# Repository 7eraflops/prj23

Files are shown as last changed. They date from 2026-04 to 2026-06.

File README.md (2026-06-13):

# 3-Phase 12-Channel ESP32 Energy Monitor

A custom ESP32-based energy meter measuring up to 12 channels across a 3-phase supply, integrated with Home Assistant via MQTT.

## Current Status
- End-to-end firmware flow is working on ESP32 DevKit: provisioning -> Wi-Fi -> MQTT -> HA discovery -> telemetry -> command handling.
- ATM90E32 real driver path is implemented (`register map`, `SPI transport`, `ATM90E32Sensor` implementing `IEnergySensor`).
- DevKit-only mock-IC path is implemented on a dedicated testing branch.
- Custom PCB and physical calibration are pending hardware availability.

## Overview
- **Measurement**: Uses the ATM90E32AS metering IC to monitor up to 12 circuits (11 used in current planned deployment).
- **Microcontroller**: ESP32-S3.
- **Integration**: Home Assistant MQTT Auto-Discovery for automatic entity configuration.
- **Provisioning**: Local captive portal and web server for Wi-Fi and MQTT setup.
- **Testing**: Uses mock sensor paths for software development before final hardware is available.

## Hardware
- **Custom PCB**: Currently in development.
- **MCU**: ESP32-S3
- **Metering IC**: ATM90E32AS
- **Sensors**: Current Transformers (CT Clamps) and Voltage Dividers

## Firmware Architecture
- `config_manager`: NVS-backed configuration (Wi-Fi, MQTT, channel phase assignment, active mask, calibration groundwork)
- `wifi_manager`: station lifecycle and reconnection
- `mqtt_manager`: client lifecycle, subscribe/publish, callback handling
- `ha_discovery`: Home Assistant discovery payload publishing
- `command_handler`: command topic handling and runtime config updates
- `sensor_manager`: polling task and telemetry publishing loop
- `atm90e32_interface`: register definitions, SPI transport, device abstraction
- `web_server`: provisioning/config pages and OTA endpoint

## Software Stack
- **Framework**: ESP-IDF (C/C++)
- **RTOS**: FreeRTOS
- **Communication**: MQTT (Mosquitto), HTTP (Local Web Server)
- **Data Processing**: Non-Intrusive Load Monitoring (NILM) runs server-side (Home Assistant / Raspberry Pi), not on the ESP32.

---

## Project Roadmap

### Phase 1: Software Foundation & HA Integration (Completed)
*Goal: Build the end-to-end data pipeline on the DevKit using mocked data before the physical hardware arrives.*

- [x] **Config & Provisioning (`config_manager`, `web_setup`)**
  - Save/load Wi-Fi and MQTT credentials using NVS.
  - Initial captive portal for device provisioning.
- [x] **MQTT Manager (`mqtt_manager`)**
  - Implement `esp_mqtt_client` using credentials from `config_manager`.
  - Handle connect/disconnect events and auto-reconnection logic.
- [x] **Home Assistant Auto-Discovery (`ha_discovery`)**
  - Implement HA MQTT Auto-Discovery protocol.
  - Publish JSON configuration payloads for Voltage, Current, Active Power, etc.
- [x] **Hardware Abstraction & Mock Sensor (`sensor_manager`)**
  - Define a generic sensor interface (`IEnergySensor`).
  - Create a `DummyEnergySensor` that generates fluctuating test data.
  - Implement a FreeRTOS telemetry task to poll the sensor and publish JSON payloads.

### Phase 2: Pre-Hardware System Features (Mostly Completed)
*Goal: Implement system-level features that can be tested on an ESP32 dev board before the custom PCBs arrive.*

- [x] **Continuous Web Server**
  - Keep web server active on the local network post-provisioning.
- [x] **Over-The-Air (OTA) Updates**
  - Implement OTA flashing mechanism.
  - Add an `/update` endpoint to the local web server to allow uploading firmware binaries.
- [x] **Two-Way MQTT Communication (Device Control)**
  - Add Home Assistant "Button" entities via HA Discovery (e.g., "Reboot").
  - Subscribe to command topics in `mqtt_manager` and execute device actions.
- [x] **Calibration Storage Groundwork**
  - Add NVS fields in `config_manager` for per-channel calibration settings.
- [X] **Calibration Web UI**
  - Add a `/calibration` web page to view and edit multipliers dynamically.

### Phase 3: Hardware Driver Preparation (In Progress)
*Goal: Write and validate the ATM90E32AS SPI driver path before custom hardware arrives.*

- [x] **ATM90E32AS Register Map**
  - Create header files defining register addresses and constants for status, calibration, instant values, power, and energy.
- [x] **SPI Interface**
  - Initialize the ESP32-S3 SPI master peripheral for shared bus + per-chip CS.
  - Implement low-level `read16()` and `write16()` functions and split-register 32-bit reads.
- [x] **ATM90E32 Sensor Implementation**
  - Create `ATM90E32Sensor` implementing `IEnergySensor`.
  - Integrate channel phase assignment and active mask behavior with existing runtime config.
- [x] **DevKit Mock IC Validation Path**
  - Add register-level ATM90E32 emulation path on testing branch to simulate fluctuating values and command/read flow.
- [ ] **Hardware Profile Finalization**
  - Finalize tuned mode/gain/threshold values when PCB and front-end are finalized.

### Phase 4: Hardware Bring-Up & Validation
*Goal: Validate the custom PCB and physically calibrate the sensors.*

- [X] **Physical Bring-Up**
  - Solder and power the PCB.
  - Validate SPI communication (e.g., read ATM90E32AS status/identity paths).
- [ ] **Live Calibration**
  - Connect actual loads and adjust multipliers via the Calibration Web UI.
  - Verify baseline noise and power factor readings.

### Phase 5: Non-Intrusive Load Monitoring (NILM)
*Goal: Differentiate multiple appliances sharing the same electrical circuit.*

#### ESP32 Responsibility (Data Provider)
The ESP32 acts as a high-fidelity data provider to Home Assistant. To aid in NILM separation, it publishes high-frequency updates (1-2 second intervals) per channel, including:
1. Active Power (W)
2. Reactive Power (var)
3. Apparent Power (VA)
4. Power Factor
5. Voltage (V) & Current (A)
6. Energy (kWh) & Frequency (Hz)
*(It also publishes device-level diagnostics like MCU temp, Wi-Fi RSSI, uptime, and free heap).*

#### Server Responsibility (Raspberry Pi 5 / Home Assistant)
Algorithms run on the server using Python (e.g., AppDaemon, custom HA integration, or NILMTK).

- [ ] **Circuit 1: Fridge (Compressor) + Coffee Maker (Resistive Heater)**
  - *Approach:* Step-Detection.
  - *Logic:* Detect flat active-power spikes (Coffee Maker) vs. reactive-power curves (Fridge). Subtract static loads to isolate devices.
- [ ] **Circuit 2: Washing Machine + Heat Pump Dryer**
  - *Approach:* State-Tracking ML Model (HMM / LSTM).
  - *Logic:* Train models on historical data to identify overlapping cycles based on combined Active and Reactive power footprints.

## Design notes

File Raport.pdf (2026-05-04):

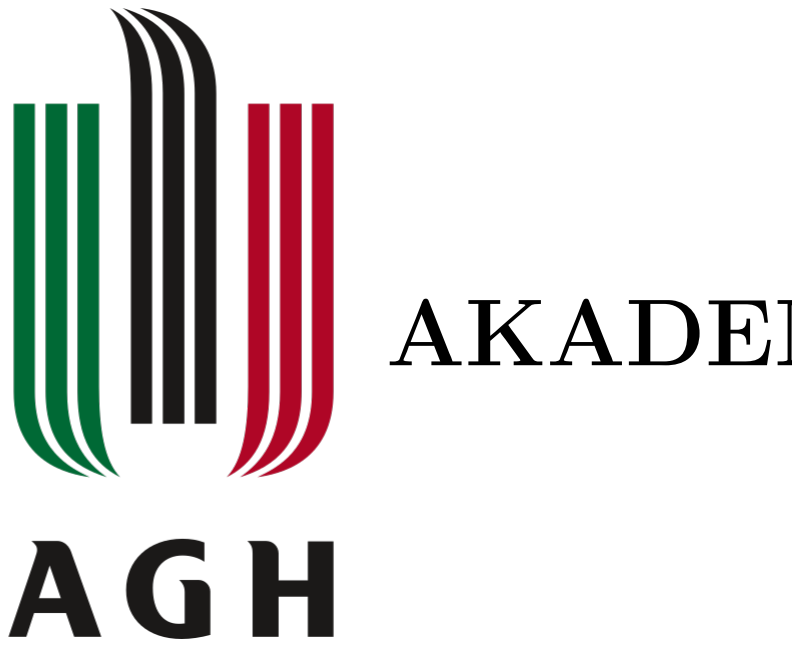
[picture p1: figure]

## AKADEMIA GÓRNICZO-HUTNICZA

## Raport z projektu

# Monitor energii 3-fazowej oparty na ESP32

z przedmiotu

## Sensory w Aplikacjach Wbudowanych

Elektronika i Telekomunikacja - Systemy Wbudowane, rok I studiów magisterskich

## Michał Charaszkiewicz

19.04.2026 r.

## Spis treści

1 Opis i założenia projektu | 2
2 Sprzęt | 3
3 Oprogramowanie | 5
4 Uruchomienie | 6
5 Bibliografia | 7

### 1. Opis i założenia projektu

### 1.1. Założenia projektowe i wysokopoziomowy opis projektu

Celem projektu jest stworzenie wielokanałowego systemu do monitorowania zużycia energii elektrycznej w instalacji trójfazowej. System umożliwia pomiar parametrów elektrycznych dla wielu obwodów jednocześnie oraz ich integrację z systemem automatyki domowej Home Assistant.

Projekt obejmuje budowę kompletnego rozwiązania składającego się z warstwy sprzętowej (dedykowana płytka PCB) oraz warstwy programowej (firmware mikrokontrolera oraz integracja z systemem nadrzędnym).

Istotnym aspektem projektu jest możliwość wykorzystania zbieranych danych do analizy zużycia energii oraz zastosowania metod NILM (Non-Intrusive Load Monitoring), realizowanych po stronie systemu nadrzędnego.

### 1.1.1 Założenia projektowe odnośnie warstwy sprzętowej

- Wykorzystanie mikrokontrolera ESP32-S3
- Zastosowanie dedykowanego układu pomiarowego energii (ATM90E32AS)
- Pomiar prądu z wykorzystaniem przekładników prądowych (CT)
- Pomiar napięcia sieci z wykorzystaniem rezystancyjnych dzielników napięcia
- Możliwość pomiaru do 12 kanałów prądowych (z możliwością przypisania każdego do dowolnej z 3 faz)
- Zaprojektowanie dedykowanej płytki PCB

Wybór układu ATM90E32AS wynika z jego przeznaczenia do precyzyjnych pomiarów energii w systemach trójfazowych, poprzez odczyt parametrów takich jak moc czynna, bierna czy współczynnik mocy z jego rejestrów. Dzięki temu, nie jest konieczna implementacja algorytmów pomiarowych działających w czasie rzeczywistym po stronie mikrokontrolera.

Zastosowanie ESP32-S3 wynika z potrzeby zapewnienia odpowiedniej mocy obliczeniowej oraz wbudowanej komunikacji Wi-Fi.

### 1.1.2 Założenia projektowe odnośnie oprogramowania

- Wykorzystanie MQTT do komunikacji z Home Assistant
- Integracja z Home Assistant poprzez mechanizm MQTT Auto-Discovery
- Możliwość konfiguracji urządzenia poprzez interfejs webowy
- Obsługa aktualizacji OTA (Over-The-Air)
- Modularna architektura oprogramowania umożliwiająca łatwą rozbudowę
- Możliwość konfiguracji parametrów kalibracyjnych

Architektura systemu została zaprojektowana w sposób umożliwiający niezależny rozwój warstwy sprzętowej i programowej. Wprowadzono warstwę abstrakcji sensorów, która pozwala na integrację docelowego układu pomiarowego bez konieczności modyfikacji logiki aplikacyjnej.

### 1.2. Podział odpowiedzialności

Projekt został wykonany samodzielnie.

### 2. Sprzęt

### 2.1. Wybór komponentów

W projekcie wykorzystywana jest platforma deweloperska:

- ESP32-S3 Waveshare N16R8 DevKit

Platforma deweloperska umożliwia rozwój i weryfikację oprogramowania niezależnie od docelowej płytki PCB. Podejście to pozwala na iteracyjne rozwijanie systemu oraz wcześniejsze wykrycie problemów w warstwie programowej.

Docelowe komponenty systemu:

- Mikrokontroler: ESP32-S3
- Układy pomiarowe: 4 × ATM90E32AS (każdy obsługujący 3 kanały pomiarowe)
- Sensory: przekładniki prądowe SCT-006

Wybór przekładników prądowych wynika z ich bezpieczeństwa i łatwości instalacji.

### 2.2. Opis schematu

Projekt schematu elektrycznego realizowany jest w środowisku KiCad. Obejmuje następujące bloki funkcjonalne:

- sekcję mikrokontrolera ESP32-S3
- cztery układy pomiarowe ATM90E32AS
- tor pomiaru prądu oparty o przekładniki SCT-006 (złącza + dzielniki napięcia aby zmniejszyć napięcie do poziomu wymaganego przez ATM90E32AS + filtry)
- tor pomiaru napięcia dla trzech faz oparty o dzielniki rezystancyjne
- sekcję zasilania

PCB jest w fazie układania layoutu. Na PCB znajdują się: 2 przyciski, moduł ESP32-S3-WROOM-1, 4-krotnie powtórzony blok pomiarowy (ATM90E32AS, 3 wejścia do pomiaru prądu, oscylator, komponenty pasywne), 3 rezystancyjne dzielniki napięcia, sekcja zasilania 3-fazowe (zabezpieczenia: rezystory bezpiecznikowe, warystory, dioda TVS, prostowanie jednopołówkowe, kondensatory, filtre EMI, regulator buck obniżający napięcie do 5V (max. 500 mA). Pozostło zaprojektowanie układu obniżającego napięcie do 3.3V i poprowadzenia reszty połączeń

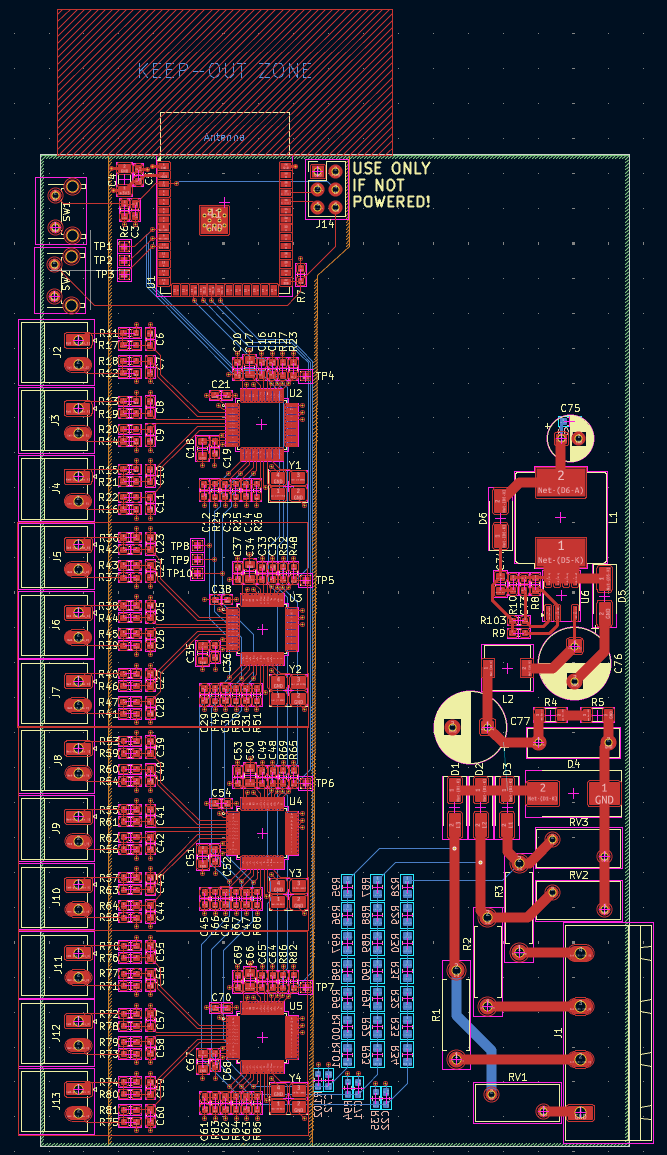
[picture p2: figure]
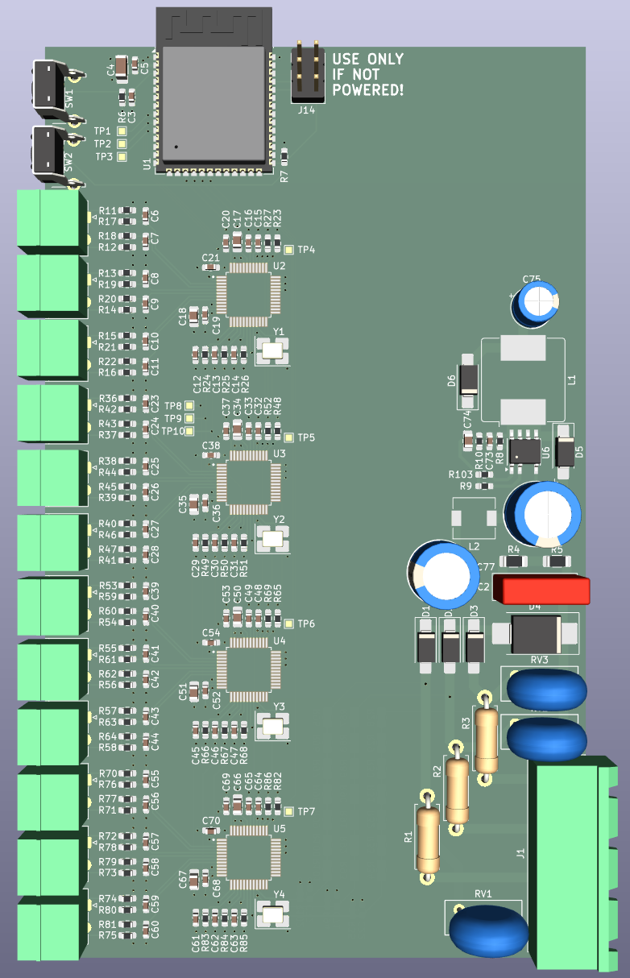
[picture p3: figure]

Rysunek 1: Layout i render 3D PCB

### 3. Oprogramowanie

### 3.1. Wykorzystane technologie

- Framework: ESP-IDF 6.0
- Język: C++
- System operacyjny: FreeRTOS
- Komunikacja: MQTT, HTTP

### 3.2. Architektura systemu

Oprogramowanie jest modularne. Główne moduły:

- config_manager – zarządzanie konfiguracją w pamięci NVS.
- wifi_manager – obsługa połączenia Wi-Fi.
- mqtt_manager – zarządzanie komunikacją MQTT.
- ha_discovery – automatyczna konfiguracja w Home Assistant.
- command_handler – obsługa komend sterujących.
- sensor_manager – zbieranie danych i publikacja telemetryczna.
- atm90e32_interface – implementacja komunikacji SPI.
- web_server – interfejs konfiguracyjny HTTP.
- ota_manager - obsługa aktualizacji OTA.
- board_manager - obsługa peryferiów na płytce (przycisk do resetu urządzenia).
- mdns_manager - publikacja hostname urządzenia w sieci lokalnej.

### 3.3. Zrealizowana funkcjonalność

- konfiguracja urządzenia poprzez interfejs webowy
- zapis konfiguracji w pamięci nieulotnej (NVS)
- automatyczne łączenie z siecią Wi-Fi
- komunikacja z brokerem MQTT i publikacja danych telemetrycznych
- automatyczna integracja z Home Assistant (MQTT Discovery)
- obsługa komend przychodzących z systemu nadrzędnego
- bezprzewodowa aktualizacja oprogramowania urządzenia (OTA)
- obsługa peryferiów sprzętowych (przycisk służący do resetu urządzenia)
- publikacja nazwy hosta w sieci lokalnej za pomocą protokołu mDNS

### 3.4. Warstwa sprzętowa (abstrakcja)

Zaprojektowano interfejs IEnergySensor, który umożliwia odseparowanie logiki aplikacyjnej od konkretnego układu pomiarowego. Zaimplementowano mapę rejestrów układu ATM90E32AS oraz obsługę SPI.

### 4. Uruchomienie

(Sekcja w przygotowaniu)

### 5. Bibliografia

- Dokumentacja ESP-IDF: https://docs.espressif.com/
- Dokumentacja MQTT: https://mqtt.org/
- Dokumentacja Home Assistant MQTT Discovery: https://www.home-assistant.io/docs/mqtt/discovery/ (https://www.home-assistant.io/docs/mqtt/discovery/)
- Dokumentacja ATM90E32AS: https://www.microchip.com/en-us/product/ATM90E32AS

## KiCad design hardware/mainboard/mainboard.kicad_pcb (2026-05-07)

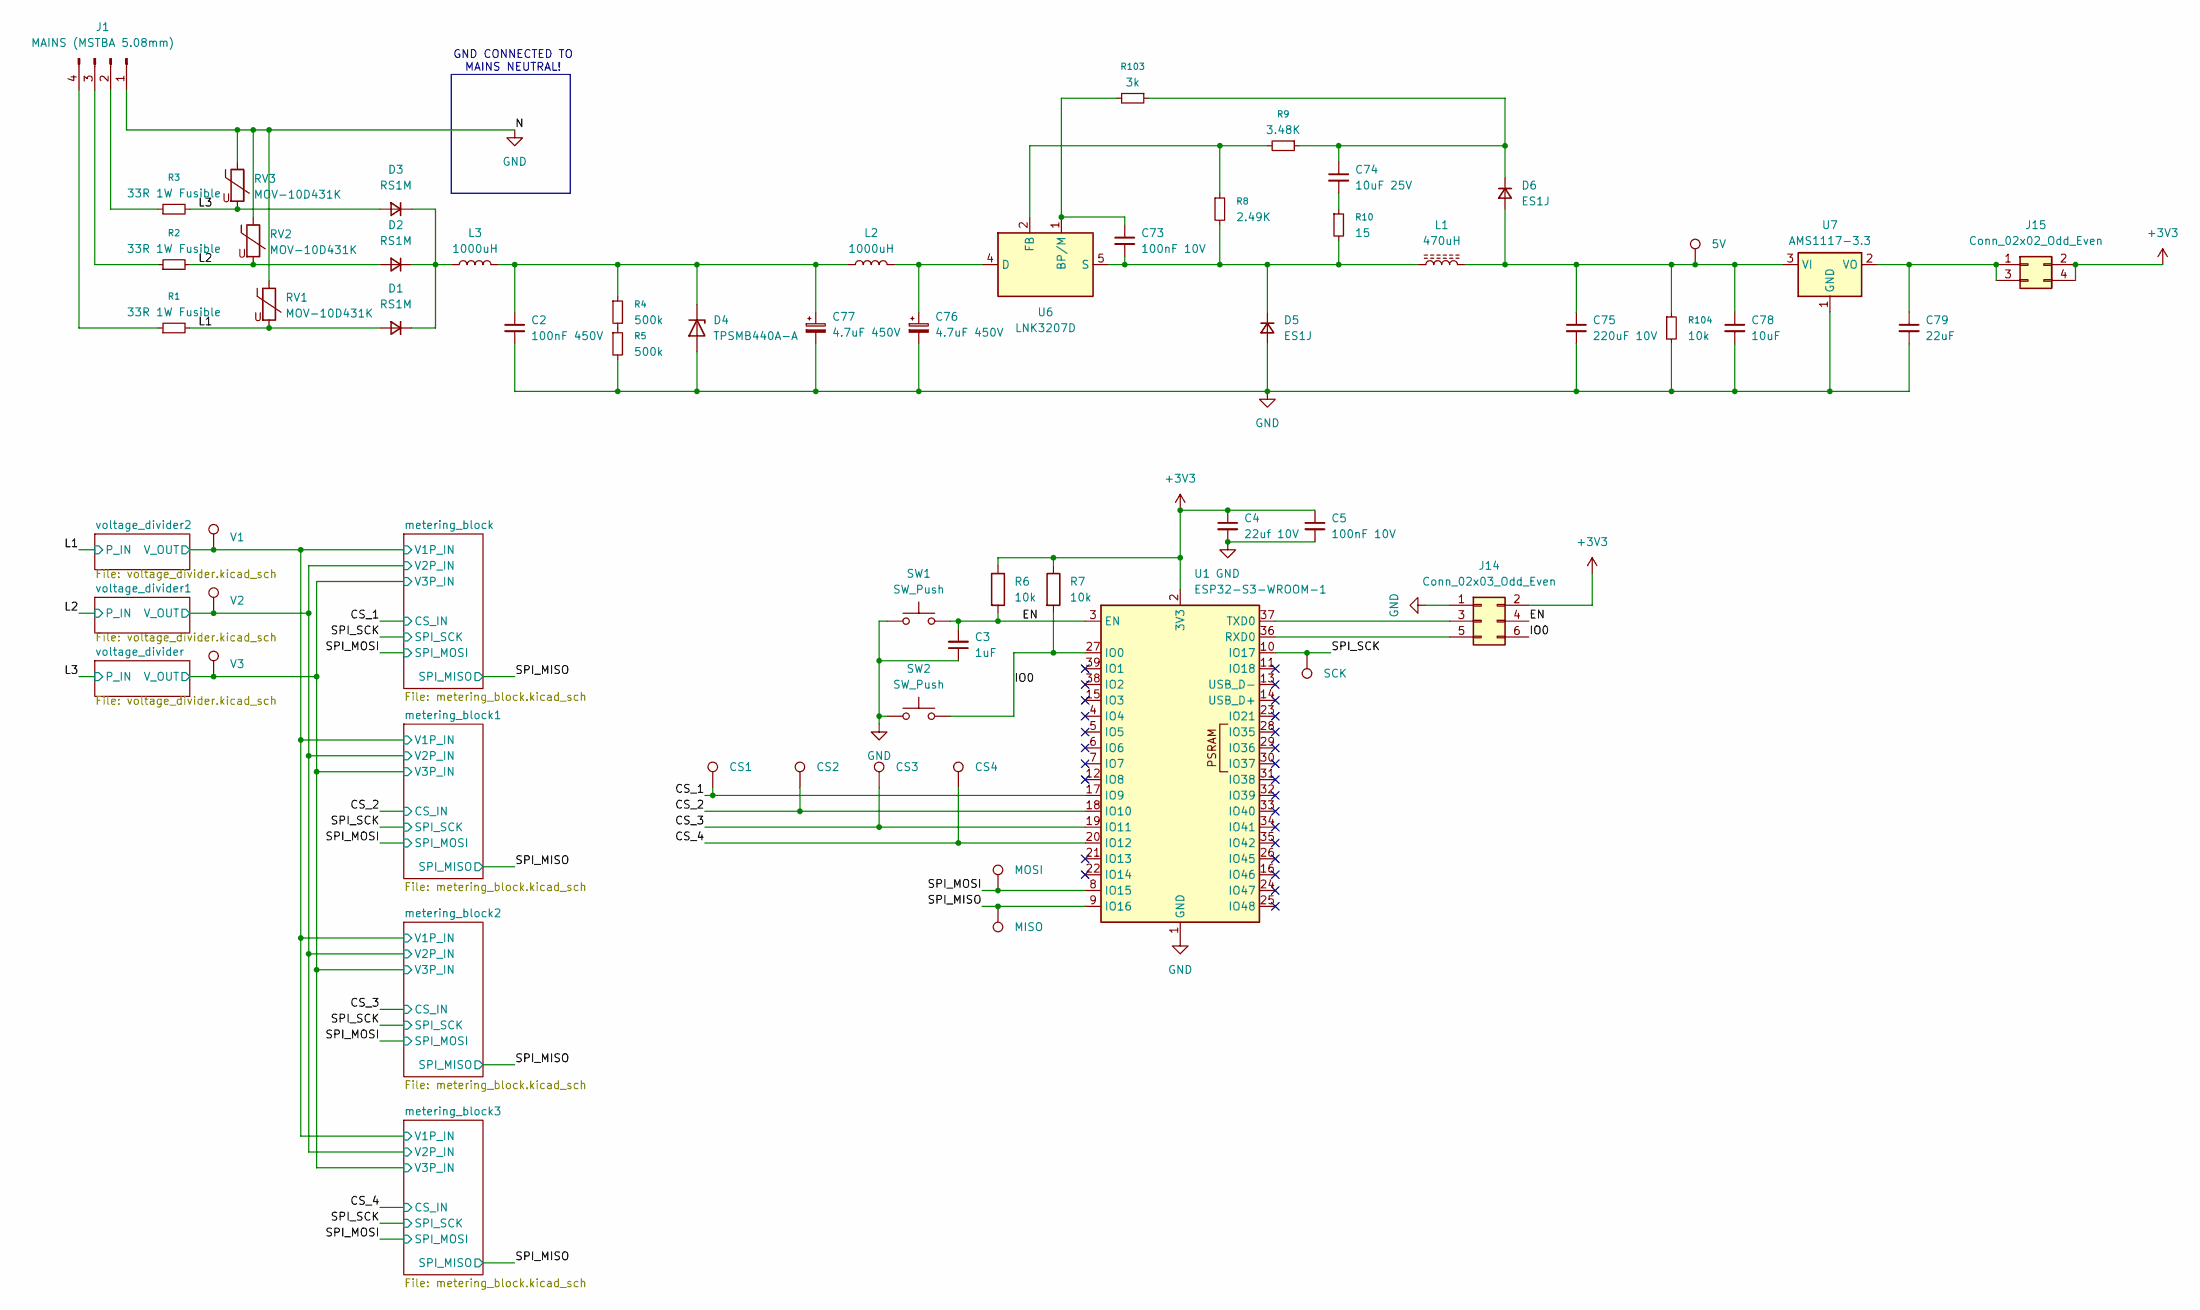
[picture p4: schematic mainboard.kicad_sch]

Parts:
C2: 100nF 450V; C_Rect_L13.0mm_W4.0mm_P10.00mm_FKS3_FKP3_MKS4
C3: 1uF; C_0603_1608Metric_Pad1.08x0.95mm_HandSolder
C4: 22uf 10V; C_1206_3216Metric_Pad1.33x1.80mm_HandSolder
C5, C73: 100nF 10V; C_0603_1608Metric_Pad1.08x0.95mm_HandSolder
C74: 10uF 25V; C_0805_2012Metric_Pad1.18x1.45mm_HandSolder
C75: 220uF 10V; CP_Radial_D6.3mm_P2.50mm
C76, C77: 4.7uF 450V; CP_Radial_D10.0mm_P5.00mm
C78: 10uF; C_0805_2012Metric_Pad1.18x1.45mm_HandSolder
C79: 22uF; C_0805_2012Metric_Pad1.18x1.45mm_HandSolder
D1, D2, D3: RS1M; D_SMA_Handsoldering
D4: TPSMB440A-A; D_SMB_Handsoldering
D5, D6: ES1J; D_SMA_Handsoldering
J1: MAINS (MSTBA 5.08mm); PhoenixContact_GMSTBA_2,5_4-G-7,62_1x04_P7.62mm_Horizontal
J14: Conn_02x03_Odd_Even; PinHeader_2x03_P2.54mm_Vertical
J15: Conn_02x02_Odd_Even; PinHeader_2x02_P2.54mm_Vertical
L1: 470uH; L_Bourns_SRR1208_12.7x12.7mm
L2, L3: 1000uH; L_6.3x6.3_H3
R1, R2, R3: 33R 1W Fusible; R_Axial_DIN0411_L9.9mm_D3.6mm_P12.70mm_Horizontal
R4, R5: 500k; R_1206_3216Metric_Pad1.30x1.75mm_HandSolder
R6, R7, R104: 10k; R_0603_1608Metric_Pad0.98x0.95mm_HandSolder
R8: 2.49K; R_0603_1608Metric_Pad0.98x0.95mm_HandSolder
R9: 3.48K; R_0603_1608Metric_Pad0.98x0.95mm_HandSolder
R10: 15; R_0603_1608Metric_Pad0.98x0.95mm_HandSolder
R103: 3k; R_0603_1608Metric_Pad0.98x0.95mm_HandSolder
RV1, RV2, RV3: MOV-10D431K; RV_Disc_D12mm_W5.4mm_P7.5mm
SW1, SW2: SW_Push; SW_Tactile_SPST_Angled_PTS645Vx58-2LFS
TP1: V1; TestPoint_Pad_1.0x1.0mm
TP2: V2; TestPoint_Pad_1.0x1.0mm
TP3: V3; TestPoint_Pad_1.0x1.0mm
TP4: CS1; TestPoint_Pad_1.0x1.0mm
TP5: CS2; TestPoint_Pad_1.0x1.0mm
TP6: CS3; TestPoint_Pad_1.0x1.0mm
TP7: CS4; TestPoint_Pad_1.0x1.0mm
TP8: SCK; TestPoint_Pad_1.0x1.0mm
TP9: MOSI; TestPoint_Pad_1.0x1.0mm
TP10: MISO; TestPoint_Pad_1.0x1.0mm
TP11: 5V; TestPoint_Pad_1.0x1.0mm
U1: ESP32-S3-WROOM-1
U6: LNK3207D; PowerIntegrations_SO-8C
U7: AMS1117-3.3; SOT-223-3_TabPin2

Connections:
+3V3: C4.1, C5.1, J14.2, J15.2, J15.4, R6.1, R7.1, U1.2 (3V3); also elsewhere on the board
/CS_1: TP4.1 (1_1), U1.17 (IO9); also elsewhere on the board
/CS_2: TP5.1 (1_1), U1.18 (IO10); also elsewhere on the board
/CS_3: TP6.1 (1_1), U1.19 (IO11); also elsewhere on the board
/CS_4: TP7.1 (1_1), U1.20 (IO12); also elsewhere on the board
/EN: C3.2, J14.4, R6.2, SW1.2, U1.3 (EN)
/IO0: J14.6, R7.2, SW2.2, U1.27 (IO0)
/L1: D1.2 (A), R1.2, RV1.2; also elsewhere on the board
/L2: D2.2 (A), R2.2, RV2.2; also elsewhere on the board
/L3: D3.2 (A), R3.2, RV3.2; also elsewhere on the board
/SPI_MISO: TP10.1 (1_1), U1.9 (IO16); also elsewhere on the board
/SPI_MOSI: TP9.1 (1_1), U1.8 (IO15); also elsewhere on the board
/SPI_SCK: TP8.1 (1_1), U1.10 (IO17); also elsewhere on the board
/metering_block/V1P_IN: TP1.1 (1_1); also elsewhere on the board
/metering_block/V2P_IN: TP2.1 (1_1); also elsewhere on the board
/metering_block/V3P_IN: TP3.1 (1_1); also elsewhere on the board
GND: C2.2, C3.1, C4.2, C5.2, C75.2, C76.2, C77.2, C78.2, C79.2, D4.2 (A), D5.2 (A), J1.1, J14.1, R5.2, R104.2, RV1.1, RV2.1, RV3.1, SW1.1, SW2.1, U1.1 (GND), U1.40 (GND), U1.41 (GND), U7.1 (GND); also elsewhere on the board
unnamed: C74.2, R10.1
unnamed: D1.1 (K), D2.1 (K), D3.1 (K), L3.1
unnamed: C2.1, C77.1, D4.1 (K), L2.1, L3.2, R4.1
unnamed: C73.2, D5.1 (K), L1.1, R8.2, R10.2, U6.5 (S), U6.6 (S), U6.7 (S), U6.8 (S)
unnamed: C75.1, C78.1, D6.2 (A), L1.2, R104.1, TP11.1 (1_1), U7.3 (VI)
unnamed: C74.1, D6.1 (K), R9.1, R103.1
unnamed: J1.2, R3.1
unnamed: J1.3, R2.1
unnamed: J1.4, R1.1
unnamed: J14.3, U1.37 (TXD0)
unnamed: J14.5, U1.36 (RXD0)
unnamed: C79.1, J15.1, J15.3, U7.2 (VO)
unnamed: R4.2, R5.1
unnamed: C73.1, R103.2, U6.1 (BP/M)
unnamed: C76.1, L2.2, U6.4 (D)
unnamed: R8.1, R9.2, U6.2 (FB)

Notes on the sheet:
GND CONNECTED TO MAINS NEUTRAL!

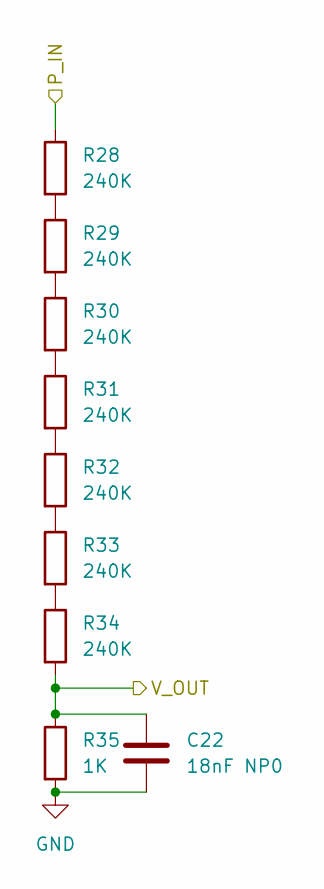
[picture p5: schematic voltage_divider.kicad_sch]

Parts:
C22: 18nF NP0; C_0603_1608Metric_Pad1.08x0.95mm_HandSolder
R28, R29, R30, R31, R32, R33, R34: 240K; R_0805_2012Metric_Pad1.20x1.40mm_HandSolder
R35: 1K; R_0603_1608Metric_Pad0.98x0.95mm_HandSolder

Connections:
/L3: R28.1; also elsewhere on the board
/metering_block/V3P_IN: C22.1, R34.2, R35.1; also elsewhere on the board
GND: C22.2, R35.2; also elsewhere on the board
unnamed: R28.2, R29.1
unnamed: R29.2, R30.1
unnamed: R30.2, R31.1
unnamed: R31.2, R32.1
unnamed: R32.2, R33.1
unnamed: R33.2, R34.1

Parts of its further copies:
C71, C72: 18nF NP0; C_0603_1608Metric_Pad1.08x0.95mm_HandSolder
R87, R88, R89, R90, R91, R92, R93, R95, R96, R97, R98, R99, R100, R101: 240K; R_0805_2012Metric_Pad1.20x1.40mm_HandSolder
R94, R102: 1K; R_0603_1608Metric_Pad0.98x0.95mm_HandSolder

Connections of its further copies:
/L1: R95.1; also elsewhere on the board
/L2: R87.1; also elsewhere on the board
/metering_block/V1P_IN: C72.1, R101.2, R102.1; also elsewhere on the board
/metering_block/V2P_IN: C71.1, R93.2, R94.1; also elsewhere on the board
GND: C71.2, C72.2, R94.2, R102.2; also elsewhere on the board
unnamed: R87.2, R88.1
unnamed: R88.2, R89.1
unnamed: R89.2, R90.1
unnamed: R90.2, R91.1
unnamed: R91.2, R92.1
unnamed: R92.2, R93.1
unnamed: R95.2, R96.1
unnamed: R96.2, R97.1
unnamed: R97.2, R98.1
unnamed: R98.2, R99.1
unnamed: R99.2, R100.1
unnamed: R100.2, R101.1

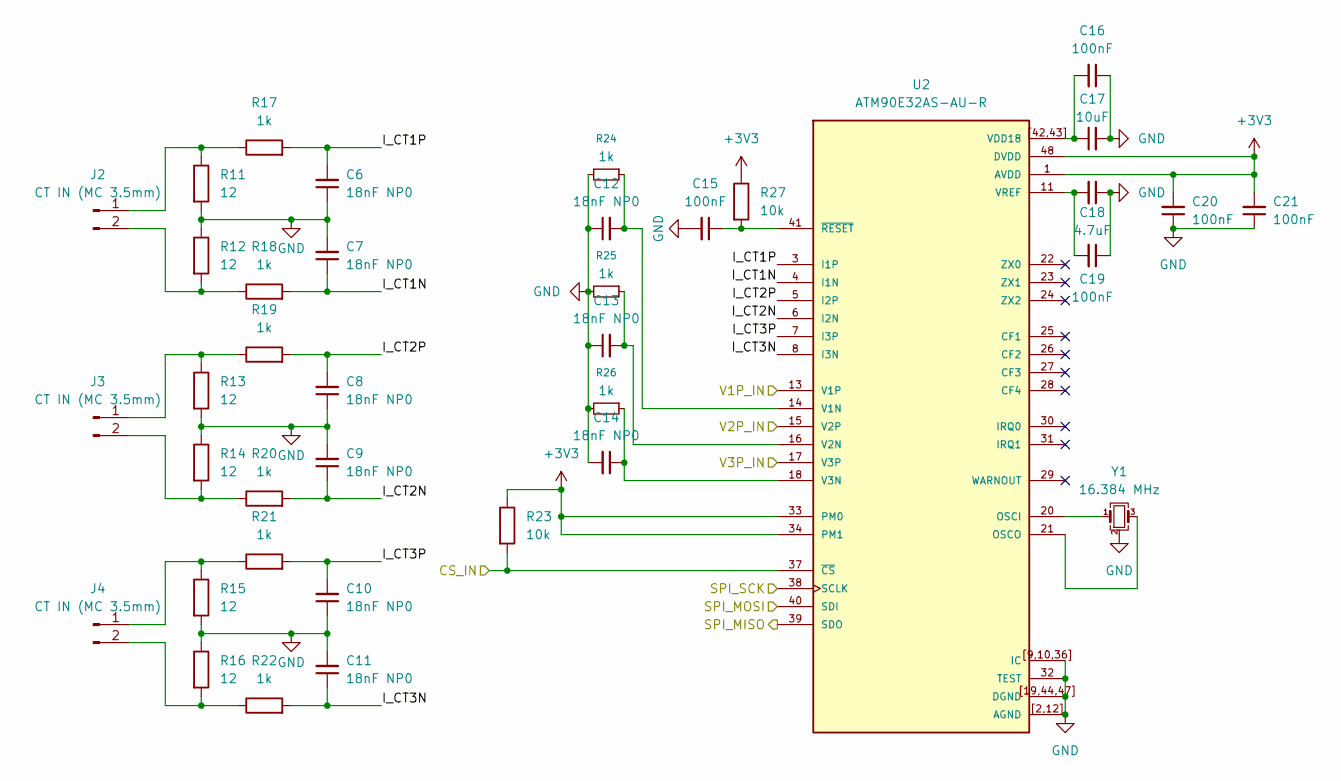
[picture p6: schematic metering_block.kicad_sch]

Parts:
C6, C7, C8, C9, C10, C11, C12, C13, C14: 18nF NP0; C_0603_1608Metric_Pad1.08x0.95mm_HandSolder
C15, C16, C19, C20, C21: 100nF; C_0603_1608Metric_Pad1.08x0.95mm_HandSolder
C17: 10uF; C_0805_2012Metric_Pad1.18x1.45mm_HandSolder
C18: 4.7uF; C_0805_2012Metric_Pad1.18x1.45mm_HandSolder
J2, J3, J4: CT IN (MC 3.5mm); PhoenixContact_MC_1,5_2-G-3.5_1x02_P3.50mm_Horizontal
R11, R12, R13, R14, R15, R16: 12; R_0603_1608Metric_Pad0.98x0.95mm_HandSolder
R17, R18, R19, R20, R21, R22, R24, R25, R26: 1k; R_0603_1608Metric_Pad0.98x0.95mm_HandSolder
R23, R27: 10k; R_0603_1608Metric_Pad0.98x0.95mm_HandSolder
U2: ATM90E32AS-AU-R; QFP50P900X900X120-48N; PARTREV 02/12/2015
Y1: 16.384 MHz; Crystal_SMD_3225-4Pin_3.2x2.5mm_HandSoldering

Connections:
+3V3: C20.2, C21.2, R23.1, R27.1, U2.1 (AVDD), U2.33 (PM0), U2.34 (PM1), U2.48 (DVDD); also elsewhere on the board
/CS_1: R23.2, U2.37 (~CS); also elsewhere on the board
/SPI_MISO: U2.39 (SDO); also elsewhere on the board
/SPI_MOSI: U2.40 (SDI); also elsewhere on the board
/SPI_SCK: U2.38 (SCLK); also elsewhere on the board
/metering_block/I_CT1N: C7.1, R18.2, U2.4 (I1N)
/metering_block/I_CT1P: C6.2, R17.2, U2.3 (I1P)
/metering_block/I_CT2N: C9.1, R20.2, U2.6 (I2N)
/metering_block/I_CT2P: C8.2, R19.2, U2.5 (I2P)
/metering_block/I_CT3N: C11.1, R22.2, U2.8 (I3N)
/metering_block/I_CT3P: C10.2, R21.2, U2.7 (I3P)
/metering_block/V1P_IN: U2.13 (V1P); also elsewhere on the board
/metering_block/V2P_IN: U2.15 (V2P); also elsewhere on the board
/metering_block/V3P_IN: U2.17 (V3P); also elsewhere on the board
GND: C6.1, C7.2, C8.1, C9.2, C10.1, C11.2, C12.1, C13.1, C14.2, C15.2, C16.1, C17.2, C18.1, C19.1, C20.1, C21.1, R11.2, R12.1, R13.2, R14.1, R15.2, R16.1, R24.2, R25.2, R26.2, U2.2 (AGND), U2.9 (IC), U2.10 (IC), U2.12 (AGND), U2.19 (DGND), U2.32 (TEST), U2.36 (IC), U2.44 (DGND), U2.47 (DGND), U2.[2,12] (AGND), U2.[9,10,36] (IC), U2.[19,44,47] (DGND), Y1.2 (G), Y1.4 (G); also elsewhere on the board
unnamed: J2.1, R11.1, R17.1
unnamed: J2.2, R12.2, R18.1
unnamed: J3.1, R13.1, R19.1
unnamed: J3.2, R14.2, R20.1
unnamed: J4.1, R15.1, R21.1
unnamed: J4.2, R16.2, R22.1
unnamed: U2.20 (OSCI), Y1.1
unnamed: U2.21 (OSCO), Y1.3
unnamed: C12.2, R24.1, U2.14 (V1N)
unnamed: C13.2, R25.1, U2.16 (V2N)
unnamed: C14.1, R26.1, U2.18 (V3N)
unnamed: C16.2, C17.1, U2.42 (VDD18), U2.43 (VDD18), U2.[42,43] (VDD18)
unnamed: C18.2, C19.2, U2.11 (VREF)
unnamed: C15.1, R27.2, U2.41 (~RESET)

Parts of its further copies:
C23, C24, C25, C26, C27, C28, C29, C30, C31, C39, C40, C41, C42, C43, C44, C45, C46, C47, C55, C56, C57, C58, C59, C60, C61, C62, C63: 18nF NP0; C_0603_1608Metric_Pad1.08x0.95mm_HandSolder
C32, C33, C36, C37, C38, C48, C49, C52, C53, C54, C64, C65, C68, C69, C70: 100nF; C_0603_1608Metric_Pad1.08x0.95mm_HandSolder
C34, C50, C66: 10uF; C_0805_2012Metric_Pad1.18x1.45mm_HandSolder
C35, C51, C67: 4.7uF; C_0805_2012Metric_Pad1.18x1.45mm_HandSolder
J5, J6, J7, J8, J9, J10, J11, J12, J13: CT IN (MC 3.5mm); PhoenixContact_MC_1,5_2-G-3.5_1x02_P3.50mm_Horizontal
R36, R37, R38, R39, R40, R41, R53, R54, R55, R56, R57, R58, R70, R71, R72, R73, R74, R75: 12; R_0603_1608Metric_Pad0.98x0.95mm_HandSolder
R42, R43, R44, R45, R46, R47, R49, R50, R51, R59, R60, R61, R62, R63, R64, R66, R67, R68, R76, R77, R78, R79, R80, R81, R83, R84, R85: 1k; R_0603_1608Metric_Pad0.98x0.95mm_HandSolder
R48, R52, R65, R69, R82, R86: 10k; R_0603_1608Metric_Pad0.98x0.95mm_HandSolder
U3, U4, U5: ATM90E32AS-AU-R; QFP50P900X900X120-48N; PARTREV 02/12/2015
Y2, Y3, Y4: 16.384 MHz; Crystal_SMD_3225-4Pin_3.2x2.5mm_HandSoldering

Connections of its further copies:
+3V3: C37.2, C38.2, C53.2, C54.2, C69.2, C70.2, R48.1, R52.1, R65.1, R69.1, R82.1, R86.1, U3.1 (AVDD), U3.33 (PM0), U3.34 (PM1), U3.48 (DVDD), U4.1 (AVDD), U4.33 (PM0), U4.34 (PM1), U4.48 (DVDD), U5.1 (AVDD), U5.33 (PM0), U5.34 (PM1), U5.48 (DVDD); also elsewhere on the board
/CS_2: R48.2, U3.37 (~CS); also elsewhere on the board
/CS_3: R65.2, U4.37 (~CS); also elsewhere on the board
/CS_4: R82.2, U5.37 (~CS); also elsewhere on the board
/SPI_MISO: U3.39 (SDO), U4.39 (SDO), U5.39 (SDO); also elsewhere on the board
/SPI_MOSI: U3.40 (SDI), U4.40 (SDI), U5.40 (SDI); also elsewhere on the board
/SPI_SCK: U3.38 (SCLK), U4.38 (SCLK), U5.38 (SCLK); also elsewhere on the board
/metering_block1/I_CT1N: C24.1, R43.2, U3.4 (I1N)
/metering_block1/I_CT1P: C23.2, R42.2, U3.3 (I1P)
/metering_block1/I_CT2N: C26.1, R45.2, U3.6 (I2N)
/metering_block1/I_CT2P: C25.2, R44.2, U3.5 (I2P)
/metering_block1/I_CT3N: C28.1, R47.2, U3.8 (I3N)
/metering_block1/I_CT3P: C27.2, R46.2, U3.7 (I3P)
/metering_block2/I_CT1N: C40.1, R60.2, U4.4 (I1N)
/metering_block2/I_CT1P: C39.2, R59.2, U4.3 (I1P)
/metering_block2/I_CT2N: C42.1, R62.2, U4.6 (I2N)
/metering_block2/I_CT2P: C41.2, R61.2, U4.5 (I2P)
/metering_block2/I_CT3N: C44.1, R64.2, U4.8 (I3N)
/metering_block2/I_CT3P: C43.2, R63.2, U4.7 (I3P)
/metering_block3/I_CT1N: C56.1, R77.2, U5.4 (I1N)
/metering_block3/I_CT1P: C55.2, R76.2, U5.3 (I1P)
/metering_block3/I_CT2N: C58.1, R79.2, U5.6 (I2N)
/metering_block3/I_CT2P: C57.2, R78.2, U5.5 (I2P)
/metering_block3/I_CT3N: C60.1, R81.2, U5.8 (I3N)
/metering_block3/I_CT3P: C59.2, R80.2, U5.7 (I3P)
/metering_block/V1P_IN: U3.13 (V1P), U4.13 (V1P), U5.13 (V1P); also elsewhere on the board
/metering_block/V2P_IN: U3.15 (V2P), U4.15 (V2P), U5.15 (V2P); also elsewhere on the board
/metering_block/V3P_IN: U3.17 (V3P), U4.17 (V3P), U5.17 (V3P); also elsewhere on the board
GND: C23.1, C24.2, C25.1, C26.2, C27.1, C28.2, C29.1, C30.1, C31.2, C32.2, C33.1, C34.2, C35.1, C36.1, C37.1, C38.1, C39.1, C40.2, C41.1, C42.2, C43.1, C44.2, C45.1, C46.1, C47.2, C48.2, C49.1, C50.2, C51.1, C52.1, C53.1, C54.1, C55.1, C56.2, C57.1, C58.2, C59.1, C60.2, C61.1, C62.1, C63.2, C64.2, C65.1, C66.2, C67.1, C68.1, C69.1, C70.1, R36.2, R37.1, R38.2, R39.1, R40.2, R41.1, R49.2, R50.2, R51.2, R53.2, R54.1, R55.2, R56.1, R57.2, R58.1, R66.2, R67.2, R68.2, R70.2, R71.1, R72.2, R73.1, R74.2, R75.1, R83.2, R84.2, R85.2, U3.2 (AGND), U3.9 (IC), U3.10 (IC), U3.12 (AGND), U3.19 (DGND), U3.32 (TEST), U3.36 (IC), U3.44 (DGND), U3.47 (DGND), U4.2 (AGND), U4.9 (IC), U4.10 (IC), U4.12 (AGND), U4.19 (DGND), U4.32 (TEST), U4.36 (IC), U4.44 (DGND), U4.47 (DGND), U5.2 (AGND), U5.9 (IC), U5.10 (IC), U5.12 (AGND), U5.19 (DGND), U5.32 (TEST), U5.36 (IC), U5.44 (DGND), U5.47 (DGND), Y2.2 (G), Y2.4 (G), Y3.2 (G), Y3.4 (G), Y4.2 (G), Y4.4 (G); also elsewhere on the board
unnamed: J5.1, R36.1, R42.1
unnamed: J5.2, R37.2, R43.1
unnamed: J6.1, R38.1, R44.1
unnamed: J6.2, R39.2, R45.1
unnamed: J7.1, R40.1, R46.1
unnamed: J7.2, R41.2, R47.1
unnamed: J8.1, R53.1, R59.1
unnamed: J8.2, R54.2, R60.1
unnamed: J9.1, R55.1, R61.1
unnamed: J9.2, R56.2, R62.1
unnamed: J10.1, R57.1, R63.1
unnamed: J10.2, R58.2, R64.1
unnamed: J11.1, R70.1, R76.1
unnamed: J11.2, R71.2, R77.1
unnamed: J12.1, R72.1, R78.1
unnamed: J12.2, R73.2, R79.1
unnamed: J13.1, R74.1, R80.1
unnamed: J13.2, R75.2, R81.1
unnamed: U3.20 (OSCI), Y2.1
unnamed: U3.21 (OSCO), Y2.3
unnamed: C29.2, R49.1, U3.14 (V1N)
unnamed: C30.2, R50.1, U3.16 (V2N)
unnamed: C31.1, R51.1, U3.18 (V3N)
unnamed: C33.2, C34.1, U3.42 (VDD18), U3.43 (VDD18)
unnamed: C35.2, C36.2, U3.11 (VREF)
unnamed: C32.1, R52.2, U3.41 (~RESET)
unnamed: U4.20 (OSCI), Y3.1
unnamed: U4.21 (OSCO), Y3.3
unnamed: C45.2, R66.1, U4.14 (V1N)
unnamed: C46.2, R67.1, U4.16 (V2N)
unnamed: C47.1, R68.1, U4.18 (V3N)
unnamed: C49.2, C50.1, U4.42 (VDD18), U4.43 (VDD18)
unnamed: C51.2, C52.2, U4.11 (VREF)
unnamed: C48.1, R69.2, U4.41 (~RESET)
unnamed: U5.20 (OSCI), Y4.1
unnamed: U5.21 (OSCO), Y4.3
unnamed: C61.2, R83.1, U5.14 (V1N)
unnamed: C62.2, R84.1, U5.16 (V2N)
unnamed: C63.1, R85.1, U5.18 (V3N)
unnamed: C65.2, C66.1, U5.42 (VDD18), U5.43 (VDD18)
unnamed: C67.2, C68.2, U5.11 (VREF)
unnamed: C64.1, R86.2, U5.41 (~RESET)

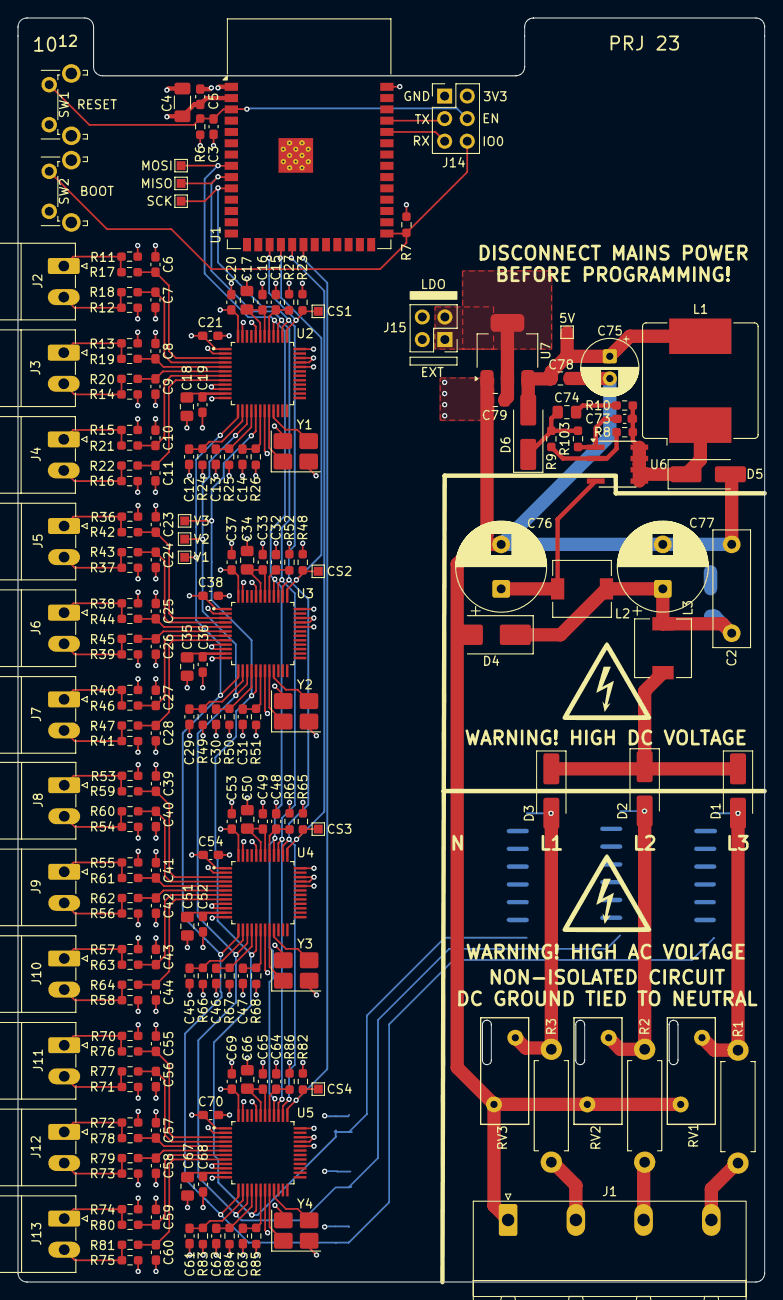
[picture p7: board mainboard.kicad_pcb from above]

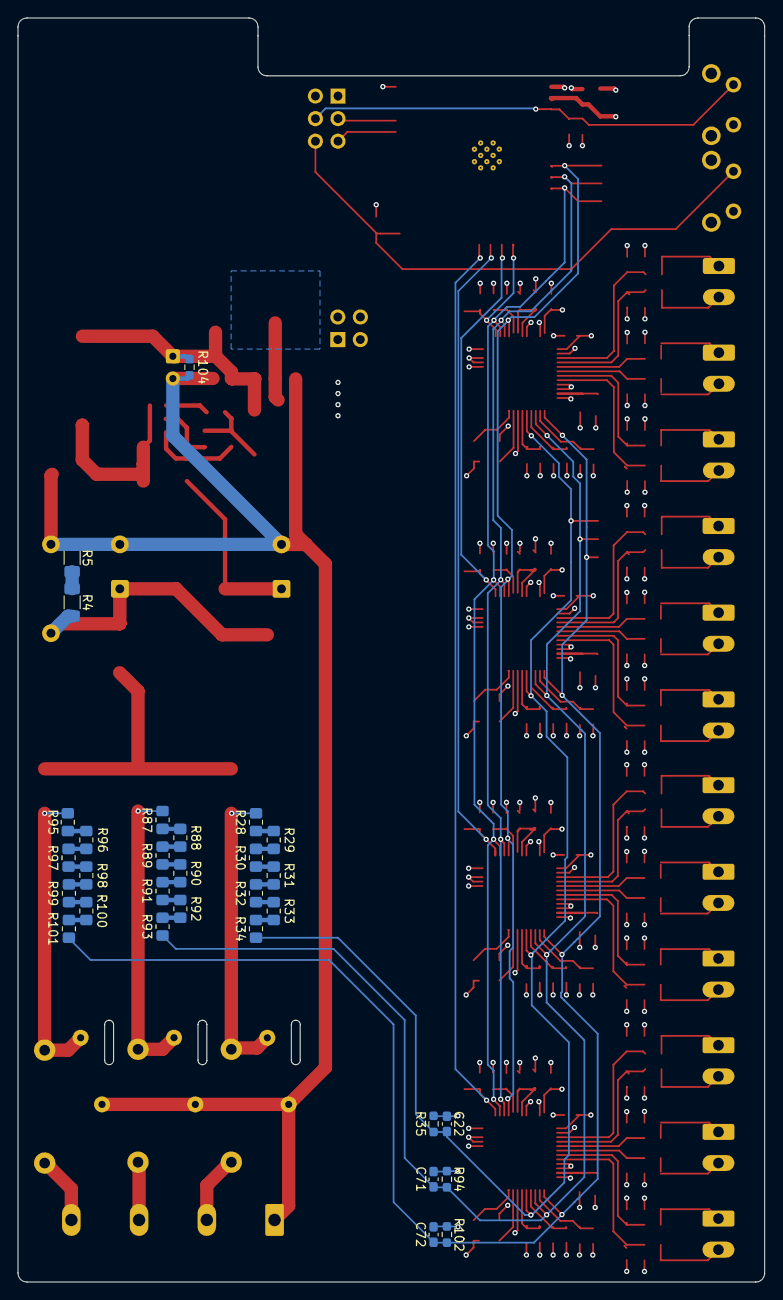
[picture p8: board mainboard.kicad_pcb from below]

Board: 4 copper layers, 84.0 x 142.2 mm, 233 parts (30 on the bottom side), 131 nets.

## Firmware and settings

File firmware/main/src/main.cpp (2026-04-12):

#include "board_manager.hpp"
#include "command_handler.hpp"
#include "config_manager.hpp"
#include "ha_discovery.hpp"
#include "mdns_manager.hpp"
#include "mqtt_manager.hpp"
#include "sensor_manager.hpp"
#include "atm90e32_sensor.hpp"
#include "web_server.hpp"
#include "wifi_manager.hpp"

#include <freertos/FreeRTOS.h>
#include <freertos/task.h>

#include <esp_log.h>
#include <esp_mac.h>
#include <esp_system.h>
#include <esp_timer.h>
#include <esp_wifi.h>

static const char* TAG = "Main";

extern "C" void app_main() {
    ESP_LOGI(TAG, "Starting Energy Meter project");

    static ConfigManager config_mgr;
    static WifiManager wifi;
    static MqttManager mqtt(config_mgr);

    uint8_t base_mac[6];
    esp_read_mac(base_mac, ESP_MAC_WIFI_STA);
    char device_id[32];
    snprintf(device_id, sizeof(device_id), "energymeter_%02x%02x%02x", base_mac[3], base_mac[4],
             base_mac[5]);
    static HaDiscovery ha_discovery(mqtt, std::string(device_id));
    static CommandHandler cmd_handler(mqtt, config_mgr, wifi, std::string(device_id));
    static auto sensor_backend = std::make_unique<ATM90E32Sensor>(config_mgr);
    static SensorManager sensor_manager(std::move(sensor_backend), mqtt, NUM_CHANNELS);

    board_manager::init_temperature_sensor();

    // Initialize reset button (GPIO 0 - BOOT button on DevKit)
    // Holding for 5 seconds will clear credentials and reboot
    board_manager::init_reset_button(GPIO_NUM_0, 5000, [&]() {
        ESP_LOGW(TAG, "Reset button held. Clearing configuration and rebooting...");
        mqtt.stop();
        wifi.set_mode(WIFI_MODE_NULL);
        config_mgr.clear();
        wifi.clear_settings();
        vTaskDelay(pdMS_TO_TICKS(200));
        esp_restart();
    });

    // Initialize WiFi and NVS
    if (wifi.init() != ESP_OK) {
        ESP_LOGE(TAG, "Failed to initialize WiFi Manager");
        return;
    }

    // Initialize mDNS Service
    if (MdnsManager::init("energy-meter") != ESP_OK) {
        ESP_LOGW(TAG, "Failed to initialize mDNS manager");
    }

    // Load saved configuration from flash memory
    config_mgr.load();

    // Always start the Web Server for local management
    if (web_server::start(wifi, config_mgr) != ESP_OK) {
        ESP_LOGE(TAG, "Failed to start Web Server");
    }

    if (config_mgr.is_configured()) {
        ESP_LOGI(TAG, "Device is configured. Connecting to Wi-Fi...");

        const AppConfig& cfg = config_mgr.get_config();

        // Turn off AP mode if we are already configured
        wifi.set_mode(WIFI_MODE_STA);
        wifi.connect(cfg.wifi_ssid, cfg.wifi_password);

        ESP_LOGI(TAG, "Waiting for WiFi connection...");
        wifi.wait_for_connection();
        ESP_LOGI(TAG, "WiFi Connected!");

        mqtt.on_message([&](const std::string& topic, const std::string& payload) {
            cmd_handler.on_message(topic, payload);
        });

        mqtt.on_connect([&]() {
            ESP_LOGI(TAG, "MQTT Connected! Publishing HA Auto-Discovery...");
            ha_discovery.publish_discovery_messages(12);
            cmd_handler.start();
            cmd_handler.publish_status();
            cmd_handler.republish_all_states();
        });

        cmd_handler.on_republish_discovery([&]() {
            ha_discovery.publish_discovery_messages(12);
        });

        if (mqtt.start() != ESP_OK) {
            ESP_LOGE(TAG, "Failed to start MQTT Manager");
        }

        if (!sensor_manager.start()) {
            ESP_LOGE(TAG, "Failed to start Sensor Manager");
        }
    } else {
        ESP_LOGI(TAG, "Device is NOT configured. Starting Provisioning AP...");

        uint8_t mac[6];
        esp_read_mac(mac, ESP_MAC_WIFI_STA);
        char ssid_buf[32];
        snprintf(ssid_buf, sizeof(ssid_buf), "Energy Meter Setup %02X%02X%02X", mac[3], mac[4],
                 mac[5]);

        std::string ap_ssid(ssid_buf);
        if (wifi.start_ap(ap_ssid) != ESP_OK) {
            ESP_LOGE(TAG, "Failed to start Access Point");
            return;
        }

        ESP_LOGI(TAG, "AP Started. Waiting for users to connect to Web Server...");
    }
    while (true) {
        ESP_LOGI(TAG, "Energy Meter heartbeat...");
        if (mqtt.is_connected()) {
            wifi_ap_record_t ap_info;
            int rssi = 0;
            if (esp_wifi_sta_get_ap_info(&ap_info) == ESP_OK) {
                rssi = ap_info.rssi;
            }
            uint32_t free_heap = esp_get_free_heap_size();
            uint32_t uptime_h = esp_timer_get_time() / 3600000000ULL;
            float mcu_temp = board_manager::get_mcu_temperature();
            uint32_t stack_min = uxTaskGetStackHighWaterMark(NULL);

            char payload[200];
            snprintf(payload, sizeof(payload),
                     "{\"status\":\"alive\",\"wifi_rssi\":%d,\"free_heap\":%lu,\"uptime\":%lu,"
                     "\"stack_min\":%lu,\"mcu_temp\":%.1f}",
                     rssi, (unsigned long)free_heap, (unsigned long)uptime_h,
                     (unsigned long)stack_min, mcu_temp);

            mqtt.publish("energy_meter/heartbeat", payload, 0, false);
        }
        vTaskDelay(pdMS_TO_TICKS(10000));
    }
}

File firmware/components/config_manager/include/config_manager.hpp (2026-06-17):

#pragma once

#include <esp_err.h>
#include <mutex>
#include <string>

static constexpr uint16_t NUM_CHANNELS = 12;

enum class ChannelPhase : uint8_t {
    NONE = 0,
    PHASE_L1 = 1,
    PHASE_L2 = 2,
    PHASE_L3 = 3
};

/**
 * @brief Holds all user-configurable parameters for the application.
 */
struct AppConfig {
    std::string wifi_ssid;
    std::string wifi_password;
    std::string mqtt_ip;
    std::string mqtt_username;
    std::string mqtt_password;

    uint16_t channel_active_mask = 0x0FFF;
    ChannelPhase channel_phases[NUM_CHANNELS];

    struct ChannelCalibration {
        float energy_offset_kwh = 0.0F;
    };

    ChannelCalibration channel_calibration[NUM_CHANNELS];

    struct CalibrationData {
        uint16_t pl_const_h = 0x0861;
        uint16_t pl_const_l = 0xC468;
        bool line_freq_50hz = true;
        uint8_t pga_gain_mode = 0;

        uint16_t p_start_th = 0x0000;
        uint16_t q_start_th = 0x0000;
        uint16_t s_start_th = 0x0000;
        uint16_t p_phase_th = 0x0000;
        uint16_t q_phase_th = 0x0000;
        uint16_t s_phase_th = 0x0000;

        int16_t p_offset[3] = {0, 0, 0};
        int16_t q_offset[3] = {0, 0, 0};
        uint16_t pq_gain[3] = {0, 0, 0};
        int16_t phi[12] = {0, 0, 0, 0, 0, 0, 0, 0, 0, 0, 0, 0};

        uint16_t u_gain[3]   = {0xC7CE, 0xC7CE, 0xC7CE};
        int16_t u_offset[3] = {0, 0, 0};
        uint16_t i_gain[12]  = {0x27A4, 0x27A4, 0x27A4, 0x27A4,
                                 0x27A4, 0x27A4, 0x27A4, 0x27A4,
                                 0x27A4, 0x27A4, 0x27A4, 0x27A4};
        int16_t i_offset[12]= {0, 0, 0, 0, 0, 0, 0, 0, 0, 0, 0, 0};
    };

    CalibrationData calibration_data;

    AppConfig() {
        for (int i = 0; i < NUM_CHANNELS; ++i) {
            if (i < 4) {
                channel_phases[i] = ChannelPhase::PHASE_L1;
            } else if (i < 8) {
                channel_phases[i] = ChannelPhase::PHASE_L2;
            } else {
                channel_phases[i] = ChannelPhase::PHASE_L3;
            }
        }
    }
};

class ConfigManager {
public:
    ConfigManager();
    ~ConfigManager();

    /**
     * @brief Loads the configuration from NVS flash into memory.
     * @return ESP_OK on success, or an appropriate esp_err_t if not found/failed.
     */
    esp_err_t load();

    /**
     * @brief Saves the current in-memory configuration to NVS flash.
     * @return ESP_OK on success, or an appropriate esp_err_t on failure.
     */
    esp_err_t save();

    /**
     * @brief Erases all saved configuration data from NVS flash.
     * @return ESP_OK on success.
     */
    esp_err_t clear();

    /**
     * @brief Checks if the minimum required configuration exists (e.g., Wi-Fi SSID is not empty).
     * @return true if configured, false otherwise.
     */
    bool is_configured() const;

    /**
     * @brief Gets a reference to the current in-memory configuration.
     */
    const AppConfig& get_config() const;

    /**
     * @brief Updates the in-memory configuration.
     * @note You must call save() after this to persist the changes to flash.
     */
    void set_config(const AppConfig& config);

    bool is_channel_active(int channel) const;
    void set_channel_active(int channel, bool active);

    ChannelPhase get_channel_phase(int channel) const;
    void set_channel_phase(int channel, ChannelPhase phase);

    void save_channel_settings();

    AppConfig::ChannelCalibration get_channel_calibration(int channel) const;
    void set_channel_calibration(int channel, const AppConfig::ChannelCalibration& calibration);
    void save_calibration_settings();

    const AppConfig::CalibrationData& get_calibration_data() const;
    void set_calibration_data(const AppConfig::CalibrationData& data);
    void save_hardware_calibration();

private:
    AppConfig _config;
    mutable std::mutex _mtx;

    // Helper methods for NVS operations
    esp_err_t load_string(const char* key, std::string& value);
    esp_err_t save_string(const char* key, const std::string& value);

    esp_err_t load_u16(const char* key, uint16_t& value);
    esp_err_t save_u16(const char* key, uint16_t value);

    esp_err_t load_u8(const char* key, uint8_t& value);
    esp_err_t save_u8(const char* key, uint8_t value);

    esp_err_t load_blob(const char* key, void* value, size_t value_size);
    esp_err_t save_blob(const char* key, const void* value, size_t value_size);

    void load_channel_settings();
    void load_calibration_settings();
    void load_hardware_calibration();
};

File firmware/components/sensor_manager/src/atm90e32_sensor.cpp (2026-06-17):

#include "atm90e32_sensor.hpp"

#include <esp_log.h>
#include <cstring>

#include <utility>

namespace {
static const char* TAG = "ATM90_SENSOR";
}

ATM90E32Sensor::ATM90E32Sensor(ConfigManager& config_manager)
    : _config_manager(config_manager), _devices{atm90e32::Device(_transport, 0),
                                                atm90e32::Device(_transport, 1),
                                                atm90e32::Device(_transport, 2),
                                                atm90e32::Device(_transport, 3)} {}

bool ATM90E32Sensor::init() {
    _last_cal = _config_manager.get_calibration_data();
    const auto& hw_cal = _last_cal;

    atm90e32::SpiBusConfig spi_cfg;
    if (_transport.init(spi_cfg) != ESP_OK) {
        ESP_LOGE(TAG, "Failed to initialize ATM90E32 SPI transport");
        return false;
    }

    constexpr uint16_t M_MODE0_50HZ = 0x0185;
    constexpr uint16_t M_MODE0_60HZ = 0x01A5;
    constexpr uint16_t M_MODE1_GAIN[] = {0x0000, 0x1555, 0x2AAA};

    const uint16_t m_mode0 = hw_cal.line_freq_50hz ? M_MODE0_50HZ : M_MODE0_60HZ;
    const uint16_t m_mode1 = (hw_cal.pga_gain_mode < 3) ? M_MODE1_GAIN[hw_cal.pga_gain_mode] : 0x0000;

    bool any_ok = false;
    for (size_t chip = 0; chip < _devices.size(); ++chip) {
        atm90e32::DeviceConfig device_cfg;
        device_cfg.pl_const_h = hw_cal.pl_const_h;
        device_cfg.pl_const_l = hw_cal.pl_const_l;
        device_cfg.line_freq_mode = m_mode0;
        device_cfg.pga_gain = m_mode1;
        device_cfg.p_start_th = hw_cal.p_start_th;
        device_cfg.q_start_th = hw_cal.q_start_th;
        device_cfg.s_start_th = hw_cal.s_start_th;
        device_cfg.p_phase_th = hw_cal.p_phase_th;
        device_cfg.q_phase_th = hw_cal.q_phase_th;
        device_cfg.s_phase_th = hw_cal.s_phase_th;

        // Hardware ADC mapping has been configured via CHANNEL_MAP_I and CHANNEL_MAP_U
        // to match Logical Line A -> Physical L1, Line B -> L2, Line C -> L3.
        // We can map calibration data directly 1:1.
        for (int i = 0; i < 3; ++i) {
            device_cfg.p_offset[i] = hw_cal.p_offset[i];
            device_cfg.q_offset[i] = hw_cal.q_offset[i];
            device_cfg.pq_gain[i] = hw_cal.pq_gain[i];
            device_cfg.voltage_gain[i] = hw_cal.u_gain[i];
            device_cfg.voltage_offset[i] = hw_cal.u_offset[i];
        }

        const size_t ch_base = chip * CHANNELS_PER_CHIP;
        for (int i = 0; i < 3; ++i) {
            device_cfg.current_gain[i] = hw_cal.i_gain[ch_base + i];
            device_cfg.current_offset[i] = hw_cal.i_offset[ch_base + i];
            device_cfg.phi[i] = hw_cal.phi[ch_base + i];
        }

        const esp_err_t err = _devices[chip].init(device_cfg);
        if (err == ESP_OK) {
            any_ok = true;
        } else {
            ESP_LOGW(TAG, "Chip %u init failed with %s",
                     static_cast<unsigned>(chip), esp_err_to_name(err));
        }
    }

    if (!any_ok) {
        ESP_LOGE(TAG, "No ATM90E32 device initialized successfully");
        return false;
    }

    ESP_LOGI(TAG, "ATM90E32 sensor initialized");
    return true;
}

ATM90E32Sensor::ChannelMap ATM90E32Sensor::map_channel(int channel) const {
    ChannelMap map{};
    map.chip_index = static_cast<std::size_t>(channel / CHANNELS_PER_CHIP);

    const int line = channel % CHANNELS_PER_CHIP;
    switch (line) {
    case 0:
        map.input = atm90e32::LineInput::A;
        break;
    case 1:
        map.input = atm90e32::LineInput::B;
        break;
    case 2:
    default:
        map.input = atm90e32::LineInput::C;
        break;
    }

    return map;
}

atm90e32::LineInput ATM90E32Sensor::phase_to_input(ChannelPhase phase,
                                                    atm90e32::LineInput fallback) const {
    switch (phase) {
    case ChannelPhase::PHASE_L1:
        return atm90e32::LineInput::A;
    case ChannelPhase::PHASE_L2:
        return atm90e32::LineInput::B;
    case ChannelPhase::PHASE_L3:
        return atm90e32::LineInput::C;
    case ChannelPhase::NONE:
    default:
        return fallback;
    }
}

void ATM90E32Sensor::update() {
    const auto& current_cal = _config_manager.get_calibration_data();
    if (std::memcmp(&_last_cal, &current_cal, sizeof(AppConfig::CalibrationData)) != 0) {
        ESP_LOGI(TAG, "Calibration data changed dynamically. Re-initializing sensors...");
        init();
        return;
    }

    for (int channel = 0; channel < TOTAL_CHANNELS; ++channel) {
        const ChannelMap map = map_channel(channel);

        if (!_config_manager.is_channel_active(channel)) {
            _channel_cache[channel] = EnergyData{};
            continue;
        }

        atm90e32::LineInput current_input = map.input;

        ChannelPhase phase = _config_manager.get_channel_phase(channel);
        atm90e32::LineInput voltage_input = phase_to_input(phase, map.input);

        atm90e32::DeviceReading reading;
        esp_err_t err = _devices[map.chip_index].read_line(current_input, reading);
        if (err != ESP_OK) {
            ESP_LOGW(TAG, "Read failed for channel %d (chip %u): %s", channel,
                     static_cast<unsigned>(map.chip_index), esp_err_to_name(err));
            _channel_cache[channel] = EnergyData{};
            continue;
        }

        if (voltage_input != current_input) {
            float phase_voltage = 0.0F;
            err = _devices[map.chip_index].read_line_voltage(voltage_input, phase_voltage);
            if (err == ESP_OK) {
                reading.voltage = phase_voltage;
                // The ATM90E32 calculates apparent/active power using the native voltage pin.
                // If we are overriding the voltage from another phase, the hardware apparent
                // power is invalid (likely 0 if the native pin is disconnected).
                reading.apparent_power = reading.voltage * reading.current;
            }
        }

        _line_cache[map.chip_index][static_cast<int>(current_input)] = reading;

        const float energy_offset = _config_manager.get_channel_calibration(channel).energy_offset_kwh;

        EnergyData out{};
        out.voltage = reading.voltage;
        out.current = reading.current;
        out.active_power = reading.active_power;
        out.reactive_power = reading.reactive_power;
        out.apparent_power = reading.apparent_power;
        out.power_factor = reading.power_factor;
        out.energy = reading.energy_kwh + energy_offset;
        out.frequency = reading.frequency;

        _channel_cache[channel] = out;
    }
}

EnergyData ATM90E32Sensor::read_channel(int channel) {
    if (channel < 0 || channel >= TOTAL_CHANNELS) {
        return EnergyData{};
    }
    return _channel_cache[channel];
}

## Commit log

2026-03-24 feat(setup): implement embedded web UI for device and MQTT provisioning
    - Implements a lightweight HTTP web server using esp_http_server.
    - Serves a bundled, single-file TypeScript/HTML frontend.
    - Provides REST endpoints to scan Wi-Fi, save settings, and reboot.
    - Adds auto-redirect capability upon successful network association.
2026-03-24 feat(mdns): add auto-discovery for MQTT and WebSocket brokers
    - Adds mdns_manager component to announce the setup UI on 'energy-meter.local'.
    - Auto-discovers local MQTT services to pre-fill the frontend form.
    - Infers MQTT protocol (ws:// vs mqtt://) from TXT records.
    - Refreshes mDNS announcements transparently when switching IP networks.
2026-03-24 feat(board): add hardware reset button handler via board_manager
    - Monitors the hardware BOOT button (GPIO 0).
    - Triggers a complete credential wipe and system reboot if held for 5 seconds.
    [board_manager.cpp]
2026-03-24 feat(main): orchestrate new web setup flow and component lifecycle
    - Replaces old setup execution with conditional Setup Portal initialization.
    - Relocates main.cpp into a src/ directory for structural consistency.
    - Wires up ConfigManager to load settings on boot.
    - Instantiates MdnsManager and BoardManager.
    [main.cpp]
2026-03-24 feat(ha): implement MQTT Auto-Discovery for Home Assistant
    - Create `HaDiscovery` component to generate Home Assistant config payloads
    - Configure 12 individual channels as sub-devices via `via_device`
    - Expose V, A, W, VA, VAR, PF, Hz, and kWh per channel
    - Add device diagnostic sensors (Uptime, Free Heap, Wi-Fi RSSI, MCU Temp)
    - Add MCU temperature sensor initialization to `board_manager`
    - Link sensor availability to device heartbeat payload
2026-03-25 chore: add private_include directory to sensor_manager
    This directory is required by CMakeLists.txt as PRIV_INCLUDE_DIRS. It will house private headers for concrete sensor implementations (like dummy_sensor and the future ATM90E32 driver) that do not nee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
2026-03-26 feat(wifi): update behavior post-setup
    Adds set_mode method to WifiManager and updates connect() to respect the current mode. This allows explicitly disabling the Access Point (AP) when the device is already configured, transitionining to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
2026-03-26 feat(web): implement tabbed management interface
    Introduces a tabbed UI for Wi-Fi and MQTT configuration. The interface automatically adapts between a linear setup wizard for unconfigured devices and a tabbed management view for configured ones, fe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
2026-03-26 feat(main): enable persistent web server and AP management
    Refactors app_main to ensure the web server is always active for local management. When a configuration is present, the device now explicitly disables the Access Point by switching to STA mode before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
2026-03-27 feat(sensor): implement core sensor manager architecture
    - Define `IEnergySensor` abstract interface for energy telemetry
    - Create `SensorManager` to orchestrate periodic sensor polling
    - Implement JSON payload formatting and MQTT publishing
    - Set up foundation for future hardware driver injection
2026-03-27 chore: allow tracking partitions.csv in gitignore
    Moves the partitions.csv exception to the ESP-IDF section and ensures it is not ignored by the broad KiCad CSV rule.
2026-03-27 feat(ota): configure 8MB flash and custom partition table
    Updates the project to target 8MB flash modules and introduces a custom partition table with dual 3MB OTA slots and a 1MB storage partition. This is required for reliable A/B firmware updates.
    [partitions.csv]
2026-03-29 build(board_manager): update driver requirements for ESP-IDF 6.0
2026-03-31 refactor(board): replace reset button polling with GPIO interrupt
    - Eliminates the InputContext memory leak by removing heap allocation entirely. All state is now static globals.
    - Replaces the dedicated 4KB-stack FreeRTOS polling task with a lightweight GPIO ISR + ESP timer. The ISR arms a one-shot timer on button press (falling edge) and disarms it on release (rising edge).
    - Adds graceful shutdown before reboot: stops MQTT, shuts down WiFi, then clears NVS and restarts.
    [board_manager.cpp, main.cpp]
2026-03-31 feat(command_handler): add two-way MQTT command handling component
    - New FreeRTOS-based command handler with dedicated task and message queue to avoid blocking the MQTT client.
    - Handles reboot, factory reset, WiFi reconnect, channel on/off, and phase assignment commands.
    - All MQTT publish and NVS write operations run in the handler task, never in the MQTT callback context.
    - Publishes state feedback to stat/ topics for Home Assistant entity synchronization.
    - Supports republish_discovery callback for triggering HA discovery from a button press.
    - Graceful shutdown before reboot: stops MQTT and WiFi before esp_restart().
2026-03-31 feat(ha_discovery): add control entities for device management
    - Add button entities: Reboot, Factory Reset (disabled by default), WiFi Reconnect, Republish Discovery.
    - Add 12 switch entities for per-channel active/inactive control (Controls section).
    - Add 12 select entities for per-channel phase assignment (Phase A/B/C/None).
    - Add configuration_url pointing to http://energy-meter.local for the Visit device link.
    - Remove Free Heap and Stack High Watermark diagnostic sensors — not useful.
    - All entities publish to the main ESP32 Energy Meter device with availability via heartbeat.
2026-03-31 feat(main): wire up command handler and MQTT subscriptions
    - Register command_handler component in build.
    - Connect MQTT on_message callback to command handler queue.
    - Trigger discovery republish and state publishing on MQTT connect/reconnect.
2026-04-12 feat(atm90e32): add multi-chip ATM90E32 sensor backend
    Introduce an ATM90E32 interface component with register definitions, SPI transport, and per-chip device reads for 4 chips on a shared SPI bus.\nIntegrate the new backend with SensorManager and app st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
2026-04-12 feat(config,mqtt): persist calibration settings and fix callback deadlock
    Add per-channel calibration storage in NVS to prepare channel-level ATM90E32 tuning without changing runtime schemas.\nRefactor MQTT callback execution to run outside internal locks so discovery and telemetry publishing no longer deadlock on connect.
    [config_manager.hpp]
2026-04-12 Docs: Update roadmap for ATM90E32 integration progress
    Reflect completed Phase 3 driver work, calibration storage groundwork, and the dedicated mock ATM90E32 testing path used on DevKit before hardware arrives.\nClarify remaining Phase 2/3 items so next 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
2026-05-04 Add PCB layout
2026-05-07 hw: Finalize PCB design
    [mainboard.kicad_pcb, mainboard.kicad_sch, metering_block.kicad_sch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]
2026-06-09 fix(spi): correct GPIO pin mapping and byte order in transfer16
    [atm90e32_spi.cpp, atm90e32_spi.hpp]
2026-06-09 calibration: set default U/I gain values for 50Hz mode
    Set initial calibration constants for voltage gain (0xC7CE) and
    current gain (0x27A4 for all 3 phases) along with line frequency
    mode (0x0185). These are starting defaults and will be refined
    through further calibration.
2026-06-09 fix(sensor): decouple phase voltage routing from physical current input
    Phase assignment (PHASE_A/B/C) was incorrectly used to select the
    entire line to read, causing both voltage and current to come from
    the phase-assigned line. This produced two bugs:
    1. Channels sharing the same phase on the same chip read identical
    current (the CT's physical line was ignored in favor of the
    phase-assigned line).
    2. Changing a channel's phase in software made its current read 0
    (the physical CT input switched to a different line).
    Fix by always reading current from the fixed physical line input
    (map.input) and reading voltage from the phase-assigned line.
    Add read_line_voltage() to the Device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
    [atm90e32_device.hpp, atm90e32_sensor.cpp]
2026-06-09 fix(phase): align phase labels with PCB (L1/L2/L3) and correct voltage mapping
    The schematic cross-wires voltage inputs: V1P=L3, V2P=L2, V3P=L1.
    Previously PHASE_A mapped to Line A (V1P = L3), so L1 voltage appeared
    on channels 9-12 instead of channels 1-4.
    Changes:
    - Rename ChannelPhase enum: PHASE_A/B/C -> PHASE_L1/L2/L3
    - Swap L1/L3 in phase_to_input: L1 -> Line C (V3P), L2 -> Line B (V2P),
    L3 -> Line A (V1P), matching PCB labels
    - Update HA select options from 'Phase A,...' to 'L1,L2,L3,None'
    - Update command handler parsing and status strings to use 'L1/L2/L3'
    With the new mapping and default config (ch1-4=L1, ch5-8=L2, ch9-12=L3),
    voltage on L1 now correctly appears on the first 4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
    [atm90e32_sensor.cpp, config_manager.hpp]
2026-06-13 docs(readme): update project status
    Mark the following tasks as completed:
    - Calibration Web UI
    - Physical Bring-Up
2026-06-17 feat(atm90e32): expand device configuration for full per-phase calibration
    - Add per-phase voltage/current gain, offset, power gain, P/Q/S offsets,
    phase angle correction, threshold registers, and checksum registers
    (CS1/CS2) to DeviceConfig.
    - Expose new register addresses: CHANNEL_MAP_I, CHANNEL_MAP_U, CS1, CS2.
    - Add post-reset delay (50 ms) for reliable chip startup.
    - Program CHANNEL_MAP_I and CHANNEL_MAP_U to correct PCB wiring:
    L1→Line C (U2), L2→Line B (U1), L3→Line A (U0) for voltage,
    while keeping current CTs with their logical phase.
    - Write all calibration registers during init and compute hardware
    checksums for data integrity.
    [atm90e32_device.hpp]
2026-06-17 feat(config): add hardware calibration blob storage via NVS
    - Introduce CalibrationData struct within AppConfig containing all
    ATM90E32 calibration parameters (gains, offsets, thresholds, phase
    angles, power constant, PGA mode, line frequency).
    - Persist CalibrationData as a binary blob in NVS under the 'hw_cal' key.
    - Add getter/setter and save_hardware_calibration() for programmatic
    access.
    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
2026-06-17 feat(sensor): integrate hardware calibration and fix phase-to-input mapping
    - Read CalibrationData from ConfigManager at init and map it to the
    per-chip DeviceConfig, supporting per-channel calibration (gain,
    offset, phase angle) across all 12 channels (4 chips × 3 phases).
    - Configure line frequency mode (50/60 Hz) and PGA gain from
    calibration data instead of hard-coded values.
    - Correct phase_to_input() mapping: L1→A, L2→B, L3→C (was wrongly
    swapping L1 and L3).
    - Fall back to V×S for apparent power when the hardware calculation
    is invalid due to voltage cross-mapping.
    - Detect calibration data changes at runtime via memcmp and
    re-initialize sensors automatically.
    - Re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
    [atm90e32_sensor.cpp]
2026-06-17 feat(web): add calibration REST API (GET/PUT /api/calibration)
    - Add GET /api/calibration handler that serializes the full
    CalibrationData (hardware calibration) plus per-channel energy
    offsets as JSON.
    - Add PUT /api/calibration handler that deserializes the JSON payload,
    applies it to the running config, and persists via ConfigManager.
    - Register both handlers and bump max_uri_handlers from 10 to 12.
2026-06-17 feat(web): add calibration UI and adopt dark theme
    - Add Calibration tab with form fields organized into collapsible
    sections: System Settings, Voltage, Current, Power, Phase,
    Energy Offsets, and Advanced.
    - Implement full calibration form logic: fetch current values from
    /api/calibration, render editable fields for all 12 channels,
    validate and submit changes back as JSON.
    - Add per-channel gain/offset grids, phase angle input with degree
    <-> register conversion (0.008789°/LSB), and combined meter
    constant field.
    - Convert the entire UI from light to dark theme (dark backgrounds,
    light text, blue accent color).
    - Refactor TypeScript: remove JSDoc noise, extract calibration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
